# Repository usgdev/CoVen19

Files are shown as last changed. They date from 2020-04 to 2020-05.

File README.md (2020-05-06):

# CoVen19
Project CoVen19 is breathing ventilator developed using standard supply already available in market easily, can be manufactured in large quantities with lowest possible resources in pandemic scenario.

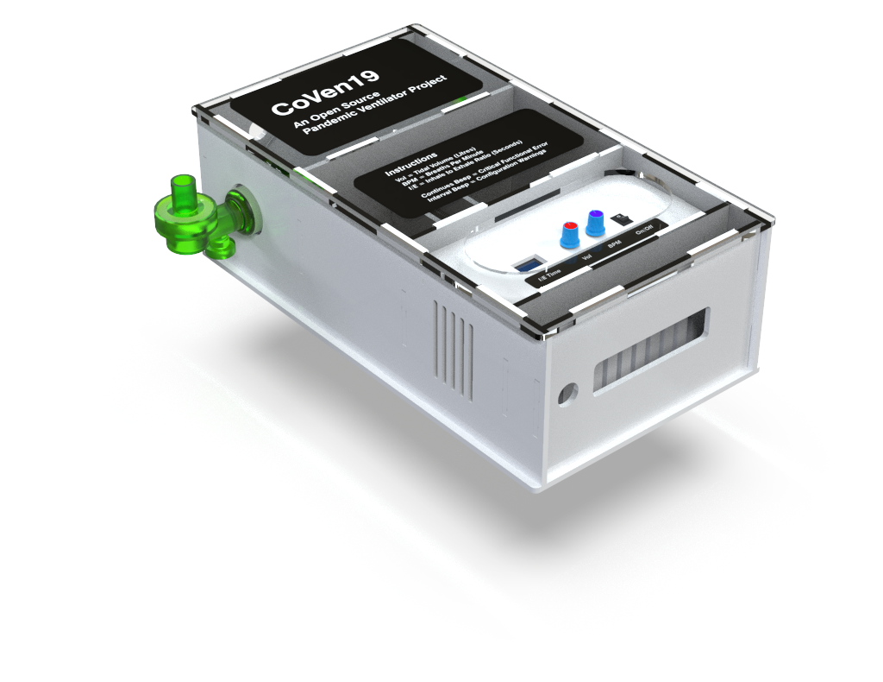
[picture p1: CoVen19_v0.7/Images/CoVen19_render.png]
CoVen19


# Current Development Version CoVen19 v0.7
CoVen19 v0.7 has following changes/updates as per latest commits:
- [x] DIY Actuator Assembly 2D DXF files Included
- [ ] Arduino UNO Firmware .ino file release(Source Code v0.7)
- [ ] Wiring schematics release(v0.7)
- [x] Updated 3D files in .STL file release
- [x] Simplified enclosure assembly design
- [x] Fixed Enclosure assembly Tab and Slot clearance
- [x] Updated BOM release in .xlsx file(v0.7)
- [x] Components reference images included

# Pandemic Ventilator Design Guideline
This is a specification of the minimally (and some preferred options) clinically acceptable ventilator to be
used in UK hospitals during the current SARS-CoV2 outbreak. It sets out the clinical requirements based on the consensus of what is ‘minimally acceptable’ performance in the opinion of the anaesthesia and intensive care medicine professionals and medical device regulators...Read more on official page https://www.gov.uk/government/publications/coronavirus-covid-19-ventilator-supply-specification/rapidly-manufactured-ventilator-system-specification

# Pandemic Ventilator Design Challenge
CoVen19 Design Challenge (https://www.youtube.com/watch?v=7vLPefHYWpY)

# What is PEEP? How to Deal with it!
## Graphics Content Warning: Demonstration video using body parts! Welcome to real medical world!
What is PEEP (https://www.youtube.com/watch?v=Gu4sChU9eBo)

# How BVM(Bag Valve Mask), PEEP Valves and Diverters works?

CoVen19 How BVM Works? (https://www.youtube.com/embed/Douv4EPk_jA)

# Source Code
### [Please find full source code here for v0.7](https://github.com/USGDEV/CoVen19/tree/master/SOURCE/Arduino/CoVen19_release_v0.7)

```C++

//Ventilator code 
//Version 1.0.0

//Breath Cycle parameters
int Inhalation_time_set[] = {1500, 1380, 1290, 1200, 1130, 1060, 1000, 950, 900}; //in milli seconds
int current_Inhalation_time = Inhalation_time_set[0];
const int current_Hold_Pause_time = 300; //Hold time does not change ever
int Exhalation_time_set[] = {3200, 2930, 2700, 2500, 2330, 2170, 2030, 1910, 1800}; //in milli seconds
int current_Exhalation_time = Exhalation_time_set[0];

//Air Volume control potentiometer parameters
int Actuator_displacement[] = {20, 40, 60, 80, 100}; //in mm
int corrent_Actuator_displacement = Actuator_displacement[0];

//Debug variables
boolean debug_output = true; //If false no serial output, to see output on serial true it

//Pin Definations
const int POT_BTH = A0;
const int POT_AVC = A1;

//Motor Related
//define Pins
int Step   =  6;
int Dir    =  7;
int MS1    =  4;
int MS2    =  5;

//define variables
int   direction        = 0;      //direction is either "0" or "1" to choose direction
float cycle            = 1;      //cycle can be in decimal 1 is 360 rotation and 0.5 is 180 degree
float time_for_cycles  = 0;      //time for total cycle is in milisecond so it can be in decimal

int   SelectResolution = 0;      //Resolution table given below
int   StepsPerRevo     = 0;

```

# Enclosure
Enclosure design based on laser cutting of 5mm acrylic or pvc sheet, normally available easily in market. 5mm sheet cutting is quick and sturdiness will be good enough to hold ventilator assembly all together, enclosure is essential to handle the ventilator without damaging internal parts.

### [Here is DXF 2D files provided for laser cutting v0.7](https://github.com/USGDEV/CoVen19/tree/master/CoVen19_v0.7/DXF)
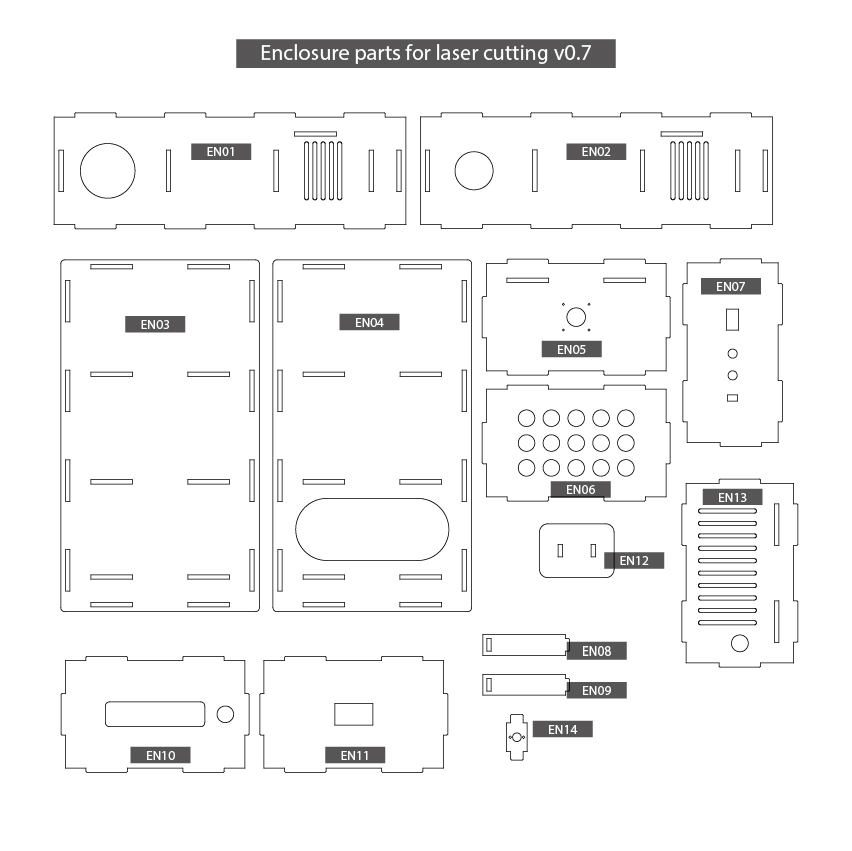
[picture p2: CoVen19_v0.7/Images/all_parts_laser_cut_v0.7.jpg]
CoVen19 Enclosure

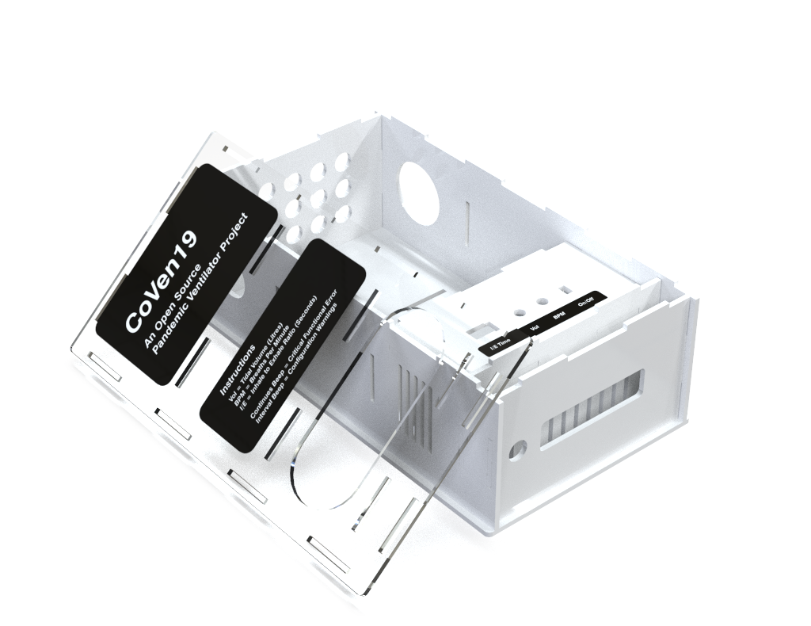
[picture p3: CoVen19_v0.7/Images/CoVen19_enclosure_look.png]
CoVen19 Enclosure


No. | ID | DXF File Name
------------ | ------------- | -------------
1 | EN01 | side_enclosure_right.DXF
2 | EN02 | side_enclosure_left.DXF
3 | EN03 | body_base_plate.DXF
4 | EN01 | body_enclosure_cover.DXF
5 | EN05 | nema_mount_plate.DXF
6 | EN06 | ambubag_air_release_plate.DXF
7 | EN07 | electronics_mount_panel.DXF
8 | EN08 | actuator_arm_left.DXF
9 | EN09 | actuator_arm_right.DXF
10 | EN10 | body_handle_plate.DXF
11 | EN11 | actuator_support_plate.DXF
12 | EN12 | pressure_plate_sloted.DXF
13 | EN13 | body_safety_plate.DXF
14 | EN14 | nut_connector_plate.DXF
    
# Components Used

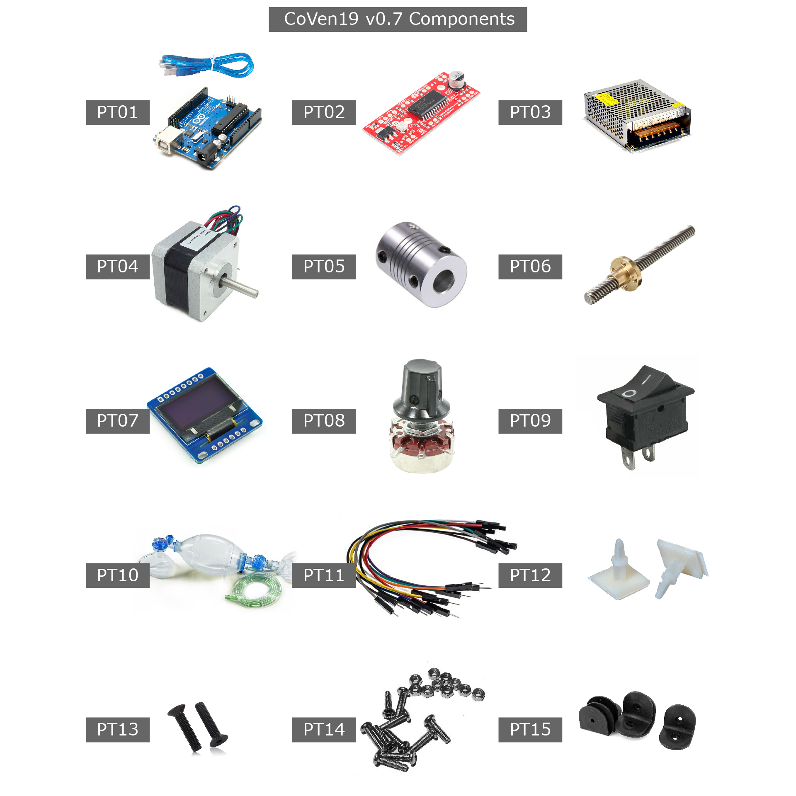
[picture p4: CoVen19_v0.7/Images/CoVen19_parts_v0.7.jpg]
CoVen19 Enclosure


No. | ID | Part Name | Ref Links/Remarks
------------ | ------------ | ------------- | -------------
1 | PT01 | Arduino UNO R3 | https://store.arduino.cc/usa/arduino-uno-rev3
2 | PT02 | SparkFun EasyDriver | https://www.sparkfun.com/products/12779
3 | PT03 | 12v Power Supply | https://www.amazon.com/MEAN-WELL-RD-65A-Output-Enclosed/dp/B005T7EZM8/
4 | PT04 | NEMA 17 Motor | Link
5 | PT05 | 5mmX8mm Coupler | Link
6 | PT06 | 8mmX100mm Lead Screw | Link
7 | PT07 | OLED 128X64 Display | Link
8 | PT08 | 100K Potentiometer | Link
9 | PT09 | Rocker Switch | Link
10 | PT10 | BVM Ambubag 350~450ml | Link
11 | PT11 | Jumper Wires | Link
12 | PT12 | PCB Self Adhesive Mounts | Link
13 | PT13 | M3X8mm Nema Mount Screw | Link
14 | PT14 | M3X10mm Bracket Nut-Bolt | Link
15 | PT15 | 90 Degree Brackets | Link

## Detailed BOM for v0.7 can be found [HERE](https://github.com/USGDEV/CoVen19/blob/master/CoVen19_v0.7/BOM/CoVen19_BOM_v0.7_r1.xlsx).

## Important Note:
**Above listed links are just for reference, You can buy components from any where you wish to.**

# Testing Equipments (Not a Part of CoVen19)
You can get a testing lungs that mimics some functions of human lung for testing your ventilator, [here is example link.](https://www.amazon.com/gp/product/B0767RBQ1H)

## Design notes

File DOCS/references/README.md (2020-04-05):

<h1>Useful Reference Links</h1>

Similar Open Source Projects
https://oedk.rice.edu/apollobvm/

<h2>Install Guides</h2>

Arduino IDE Guide
https://www.arduino.cc/en/Guide/windows

Visual Studio Install Guide (Optional)
https://www.dmcinfo.com/latest-thinking/blog/id/9484/arduino-programming-with-vscode

<h2>Arduino Code Examples</h2>

Stepper Motor Controller with SparkFun EasyDriver 
https://rudysarduinoprojects.wordpress.com/2019/07/08/fun-with-arduino-37-control-a-nema-17-stepper-motor-with-easy-driver/

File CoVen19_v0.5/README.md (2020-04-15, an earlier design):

# CoVen19 Version 0.7

# CoVen19
Project CoVen19 is breathing ventilator developed using standard supply already available in market easily, can be manufactured in large quantities with lowest possible resources in pandemic scenario.

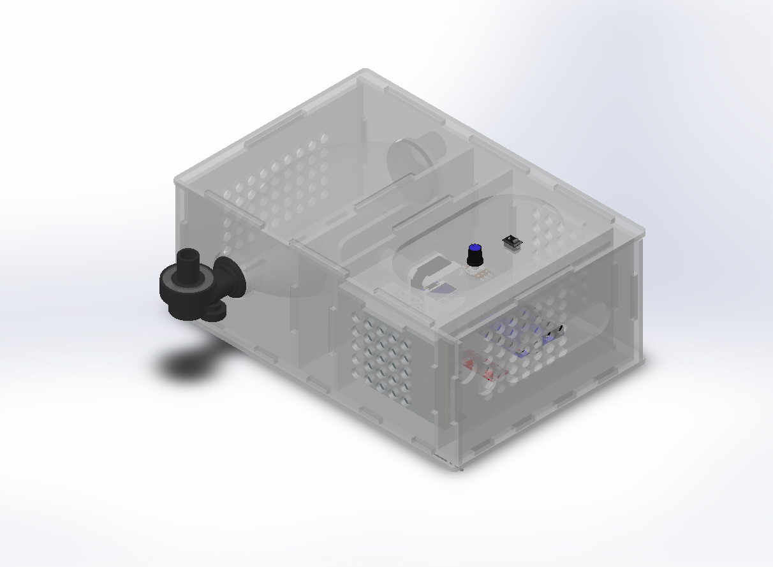
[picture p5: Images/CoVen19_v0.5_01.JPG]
CoVen19


# Pandemic Ventilator Design Guideline
This is a specification of the minimally (and some preferred options) clinically acceptable ventilator to be
used in UK hospitals during the current SARS-CoV2 outbreak. It sets out the clinical requirements based on the consensus of what is ‘minimally acceptable’ performance in the opinion of the anaesthesia and intensive care medicine professionals and medical device regulators...Read more on official page https://www.gov.uk/government/publications/coronavirus-covid-19-ventilator-supply-specification/rapidly-manufactured-ventilator-system-specification

# Pandemic Ventilator Design Challenge
CoVen19 Design Challenge (https://www.youtube.com/watch?v=7vLPefHYWpY)

# What is PEEP? How to Deal with it!
## Graphics Content Warning: Demonstration video using body parts! Welcome to real medical world!
What is PEEP (https://www.youtube.com/watch?v=Gu4sChU9eBo)

# How BVM(Bag Valve Mask), PEEP Valves and Diverters works?

CoVen19 How BVM Works? (https://www.youtube.com/embed/Douv4EPk_jA)

# Source Code
### [Please find full source code here for v0.5](https://github.com/USGDEV/CoVen19/tree/master/SOURCE/Arduino/CoVen19_release_v0.5)

```C++

//Forward/reverse stepping function
void ForwardBackwardStep()
{
  Serial.println("Alternate between stepping forward and reverse.");
  for(x= 1; x<5; x++)  //Loop the forward stepping enough times for motion to be visible
  {
    //Read direction pin state and change it
    state=digitalRead(dir);
    if(state == HIGH)
    {
      digitalWrite(dir, LOW);
    }
    else if(state ==LOW)
    {
      digitalWrite(dir,HIGH);
    }

    for(y=0; y<1000; y++)
    {
      digitalWrite(stp,HIGH); //Trigger one step
      delay(1);
      digitalWrite(stp,LOW); //Pull step pin low so it can be triggered again
      delay(1);
    }
  }
  Serial.println("Enter new option:");
  Serial.println();
}

```

# Enclosure
Enclosure design based on laser cutting of 5mm acrylic or pvc sheet, normally available easily in market. 5mm sheet cutting is quick and sturdiness will be good enough to hold ventilator assembly all together, enclosure is essential to handle the ventilator without damaging internal parts.

### [Here is DXF 2D files provided for laser cutting v0.5](https://github.com/USGDEV/CoVen19/tree/master/DXF/Laser_Cut_v0.5)

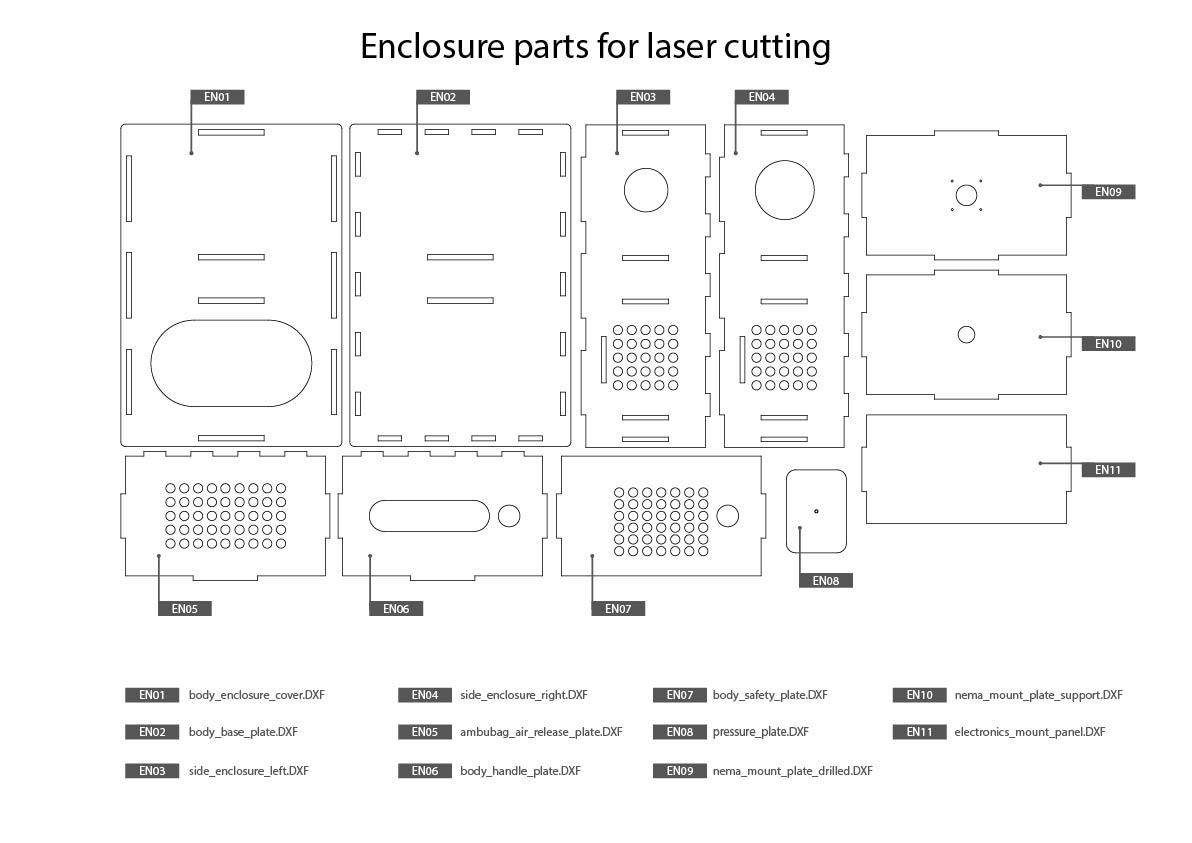
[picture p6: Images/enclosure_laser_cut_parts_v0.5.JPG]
CoVen19 Enclosure


1. ambubag_air_release_plate.DXF
2. body_base_plate.DXF
3. body_enclosure_cover.DXF
4. body_handle_plate.DXF
5. body_safety_plate_.DXF
6. electronics_mount_panel.DXF
7. nema_mount_plate_drilled.DXF
8. nema_mount_plate_support.DXF
9. pressure_plate.DXF
10. side_enclosure_left.DXF
11. side_enclosure_right.DXF

### Important Note:
**CoVen19 v0.5 enclosure design compatible with stepper motor model [LGA421S14-A-UIEV-038](https://us.nanotec.com/products/2782-lga421s14-a-uiev-038/) or motor with similar specification in order to actuator length, motor/mount screw dimensions etc. Please make sure that the stepper motor you are using is similar. OR make necessary changes to DXF files.**

LGA42 motor

Please refer detailed document and information [here](https://us.nanotec.com/products/2782-lga421s14-a-uiev-038/)

# Components Used

Component Name | Ref Links
------------ | -------------
NEMA LGA42 Motor | https://us.nanotec.com/products/2782-lga421s14-a-uiev-038/
Arduino UNO r3 | https://store.arduino.cc/usa/arduino-uno-rev3
SparkFun EasyDriver | https://www.sparkfun.com/products/12779
Generic Power Supply | https://www.amazon.com/MEAN-WELL-RD-65A-Output-Enclosed/dp/B005T7EZM8/
Ambu Bag (BVM) | https://www.amazon.com/Adult-Simple-Breathing-Apparatus-Kit/dp/B085ZLVMZ3/
Mains Power Supply Cable | https://www.secomp-international.com/en_US/roline-power-cable-with-schuko-connector-open-end-ac-230v-bl/i/19.08.1111-10
OLED Display | https://www.amazon.com/dp/B00O2LLT30
Rotary Potentiometer | https://www.amazon.in/pack-potentiometer-single-variable-resistor/dp/B07L3YQ4NT
Black Metal Knob | https://www.sparkfun.com/products/10002
Rocker Switch | https://www.sparkfun.com/products/8837
M3 Screw 8mm | https://www.amazon.com/dp/B01IWUSDYY and https://www.amazon.com/uxcell-M3x8mm-Thread-Button-Socket/dp/B01B1OD62C
90 Degree Bracket Joint | https://www.ebay.com/itm/90-Degree-Right-Angle-Stainless-Steel-Support-Shelf-Bracket-Joint-Corner-Brace-/183693072726
Acrylic sheet | https://www.amazon.com/dp/B07MWXWDKQ

### Important Note:
**Above listed links are just for reference, You can buy components from any where you wish to.**

# Testing Equipments (Not a Part of CoVen19)
You can get a testing lungs that mimics some functions of human lung for testing your ventilator, [here is example link.](https://www.amazon.com/gp/product/B0767RBQ1H)

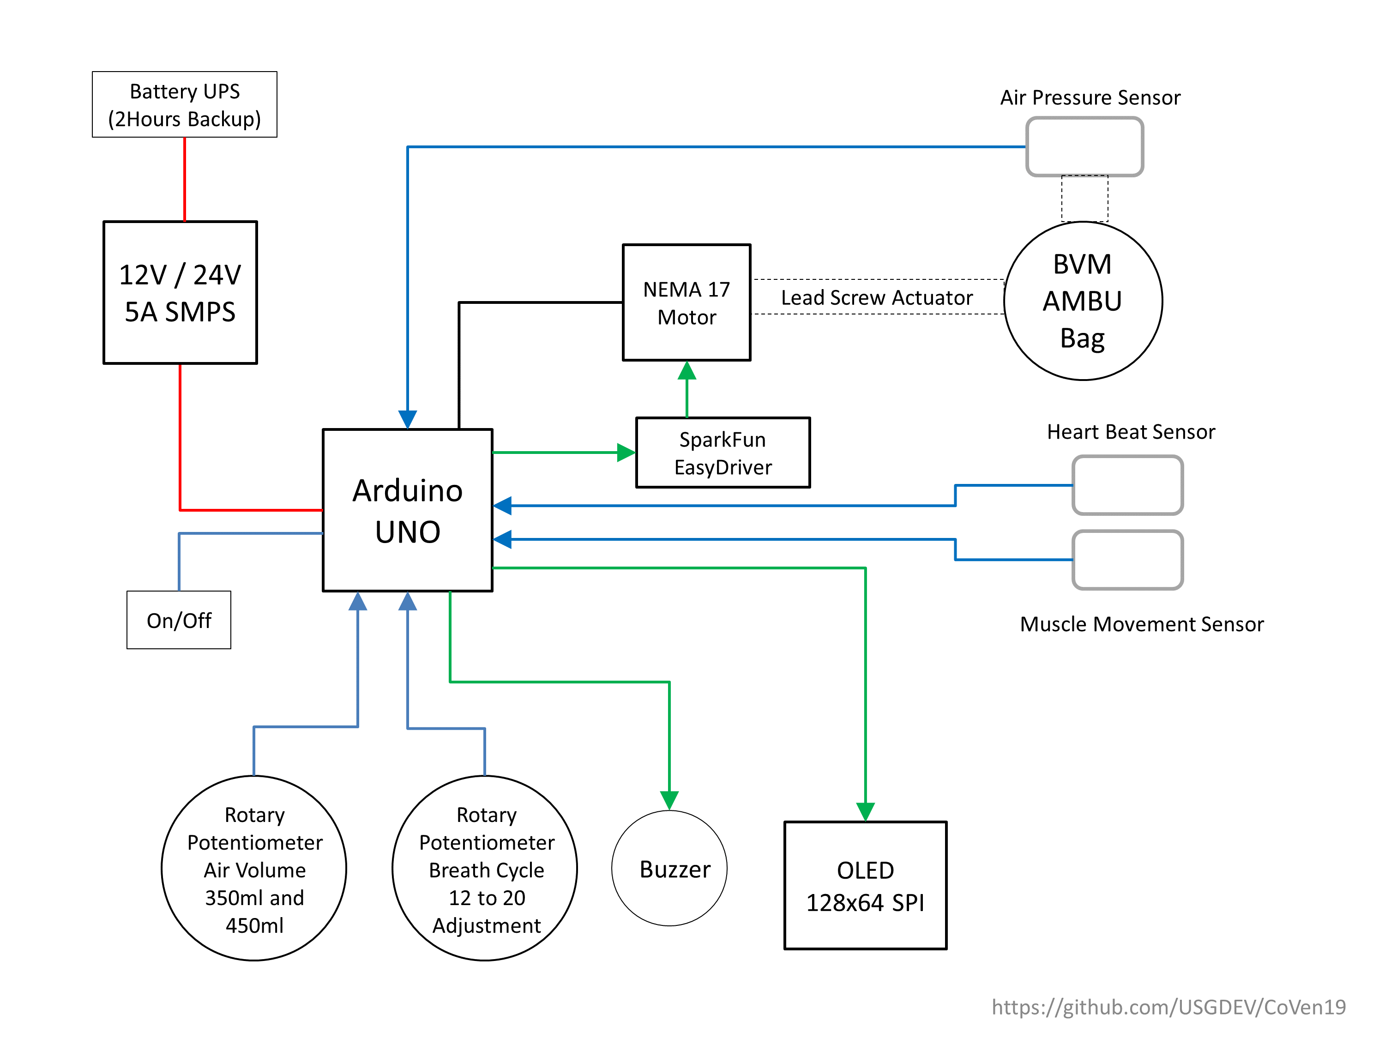
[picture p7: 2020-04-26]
DOCS/CoVen19_block_diagram_v1.png

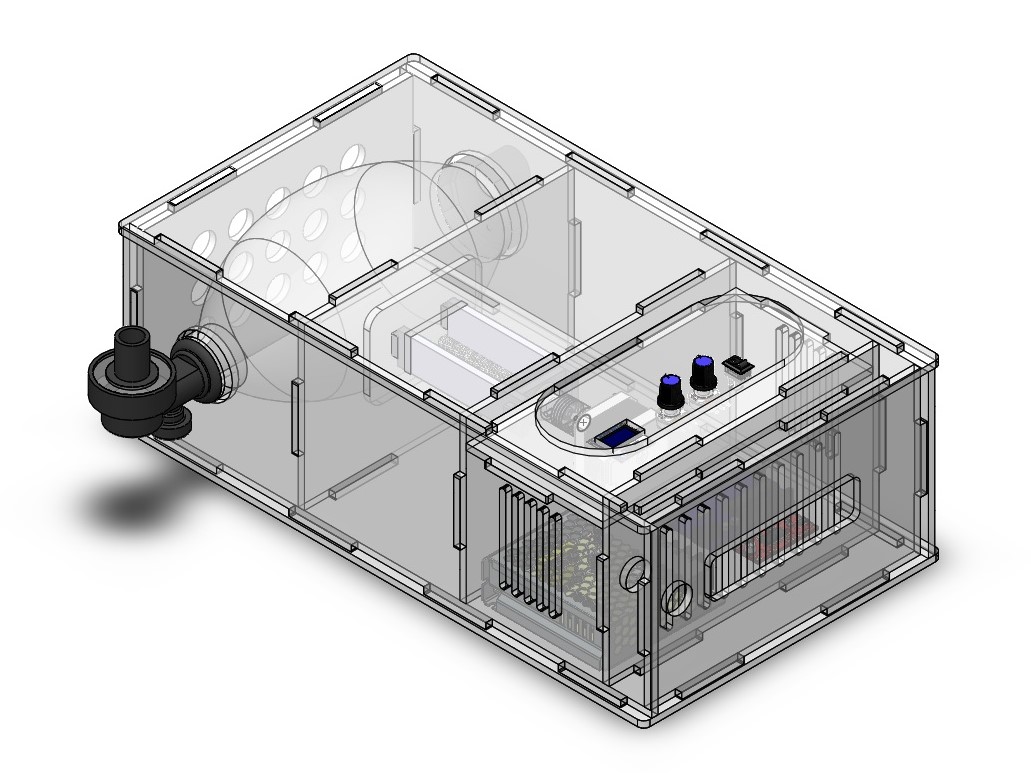
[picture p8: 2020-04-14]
CoVen19_v0.7/Images/CoVen19_v0.7_01.JPG

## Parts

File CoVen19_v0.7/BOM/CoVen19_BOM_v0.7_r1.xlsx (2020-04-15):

Sr. No. | Part Name | PART SKU/ID/Discription | Qty. | Procurement Link(s) | Remarks
 | NEMA 17 Motor | Stepper motor - NEMA-17 size - 200 steps/rev, 12V 350mA PRODUCT ID: 324 | 1 | https://www.adafruit.com/product/324
 | Arduino UNO r3 | ARDUINO UNO REV3 Code: 8058333490090 | 1 | https://store.arduino.cc/usa/arduino-uno-rev3
 | SparkFun EasyDriver | EasyDriver - Stepper Motor Driver | 1 | https://www.sparkfun.com/products/12779
 | Generic Power Supply | 12V, 3.5 Amp Single Output Switching Power Supply (Item #PS1-40W-SL12) | 1 | https://www.circuitspecialists.com/12-volt-3.5-amp-power-supply.html
 | Ambu Bag (BVM) | Generic Adult BVM Ambu Bag | 1 | https://www.amazon.com/Silica-Manual-Simple-Breathing-Oxygen/dp/B0862CL1YB?me= | Any BVM adult Ambu Bag Should Work
 | Mains Power Supply Cable | Generic Power supply cable | 1
 | OLED Display | Generic Arduino Compitible OLED 128x64 Display | 1 | https://www.dnatechindia.com/6-pin-128-64-white-oled-display.html
 | Rotary Potentiometer | Rotary Potentiometer | 1 | https://www.sparkfun.com/products/9939
 | Black Metal Knob | Black Metal Knob - 14x24mm | 1 | https://www.sparkfun.com/products/10002
 | Rocker Switch | Rocker Switch | 1 | https://www.sparkfun.com/products/8837
 | M3 Screw 8mm | M3 Screw 8mm screw for nema 17 motor mounting | 4 | https://www.aliexpress.com/item/32778526710.html
 | 90 Degree Bracket Joints | Brackets for securing enclosure parts | 10 | https://www.ebay.com/itm/90-Degree-Right-Angle-Stainless-Steel-Support-Shelf-Bracket-Joint-Corner-Brace-/183693072726 | Approx
 | Screw for Braket Joints | Generic nut bots compitibal with Bracket | 60
 | Acrylic sheet | 5 mm acrylic sheet for laser cutting |  |  | Laser cutting as per DXF file provided with this project

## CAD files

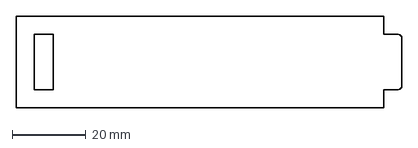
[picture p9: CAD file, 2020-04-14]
CoVen19_v0.7/DXF/actuator_arm_left.DXF
105.0 x 25.0 mm

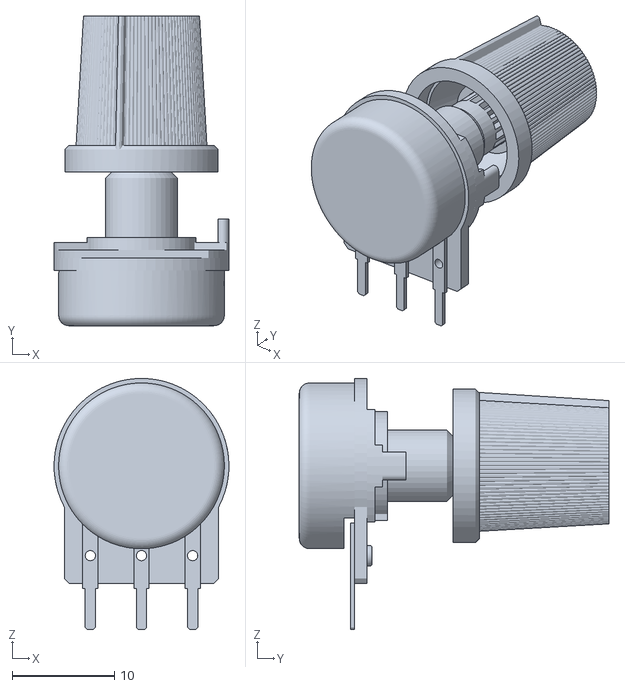
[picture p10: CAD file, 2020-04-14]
CoVen19_v0.7/STL/potentiometer_breathing_speed-1.STL
17.1 x 30.3 x 24.5

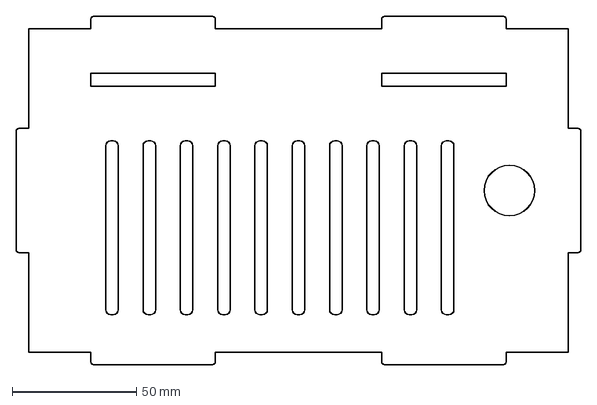
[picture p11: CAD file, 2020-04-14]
CoVen19_v0.7/DXF/body_safety_plate.DXF
227.0 x 140.0 mm

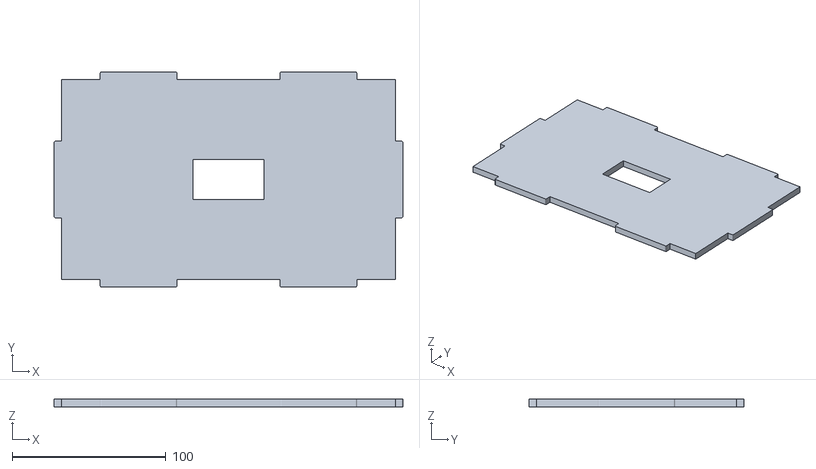
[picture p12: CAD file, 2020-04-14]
CoVen19_v0.7/STL/actuator_support_plate-1.STL
227.0 x 140.0 x 5.00

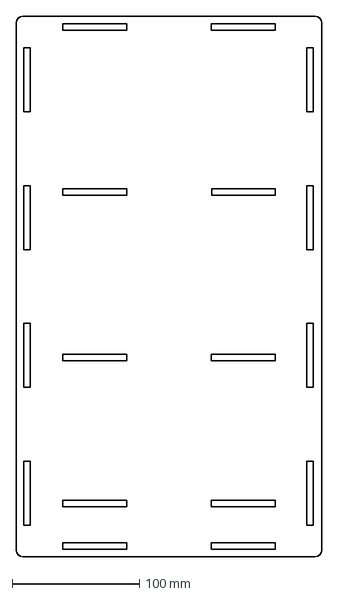
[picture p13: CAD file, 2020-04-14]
CoVen19_v0.7/DXF/body_base_plate.DXF
240.0 x 425.0 mm

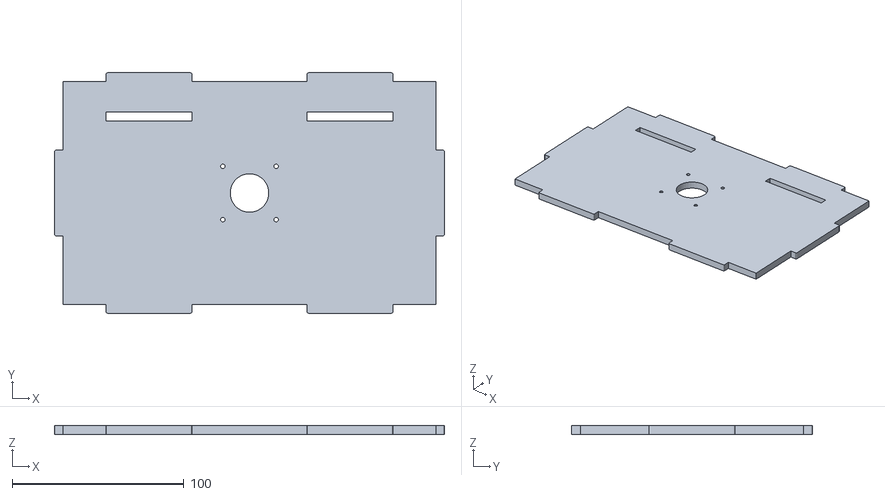
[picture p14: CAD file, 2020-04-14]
CoVen19_v0.7/STL/nema_mount_plate-1.STL
227.0 x 140.0 x 5.00

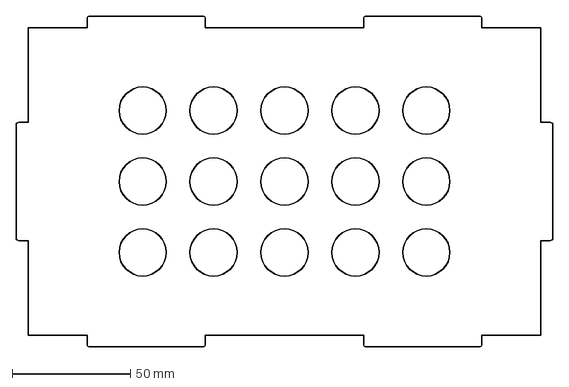
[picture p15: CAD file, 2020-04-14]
CoVen19_v0.7/DXF/ambubag_air_release_plate.DXF
227.0 x 140.0 mm

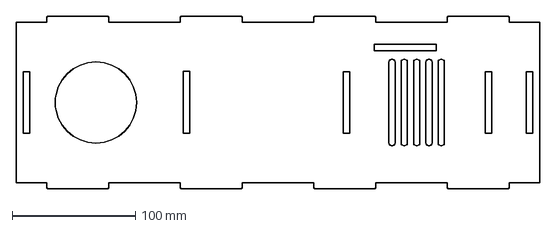
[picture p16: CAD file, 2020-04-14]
CoVen19_v0.7/DXF/side_enclosure_right.DXF
425.0 x 140.0 mm

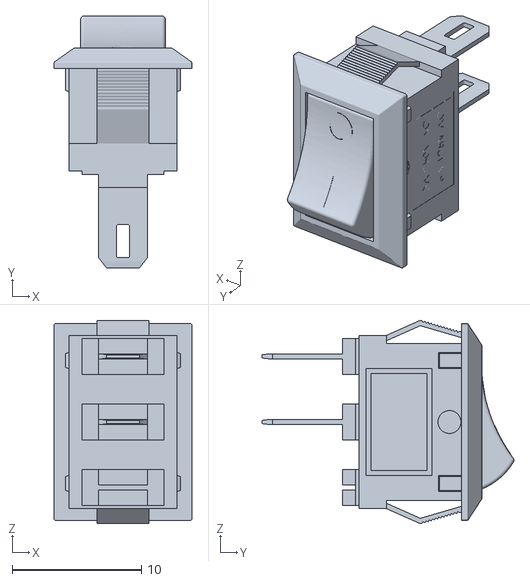
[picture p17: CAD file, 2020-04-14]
CoVen19_v0.7/STL/Rocker_Switch-1.STL
10.7 x 19.5 x 15.7

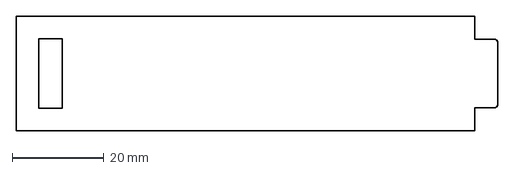
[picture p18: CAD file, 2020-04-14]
CoVen19_v0.7/DXF/actuator_arm_right.DXF
105.0 x 25.0 mm

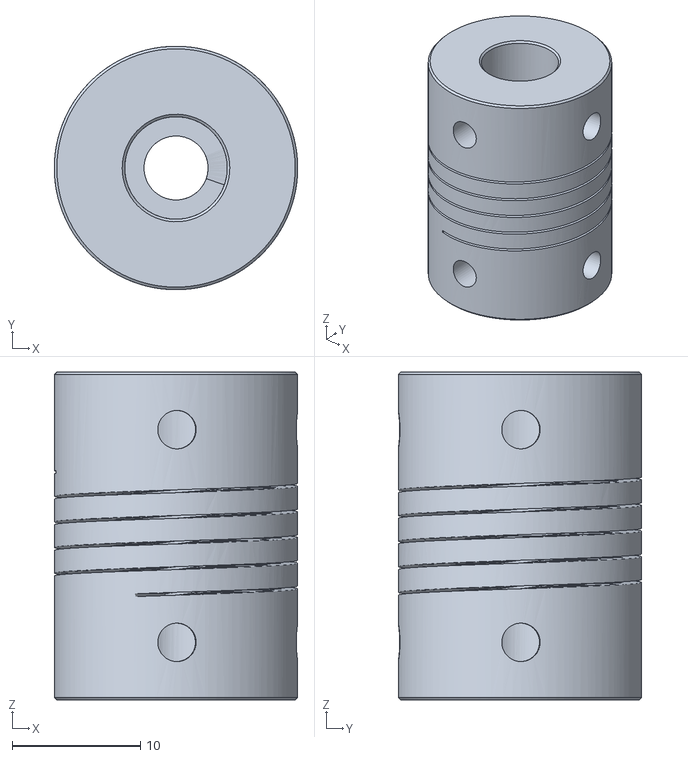
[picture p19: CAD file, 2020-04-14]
CoVen19_v0.7/STL/nema_coupler_5x8mm-1.STL
19.0 x 19.0 x 25.6

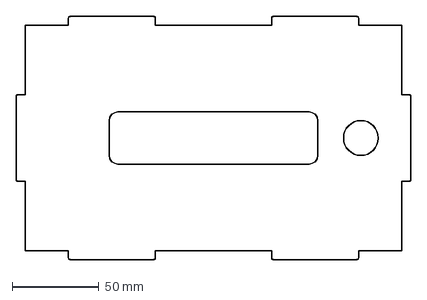
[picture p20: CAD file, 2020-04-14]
CoVen19_v0.7/DXF/body_handle_plate.DXF
227.0 x 140.0 mm

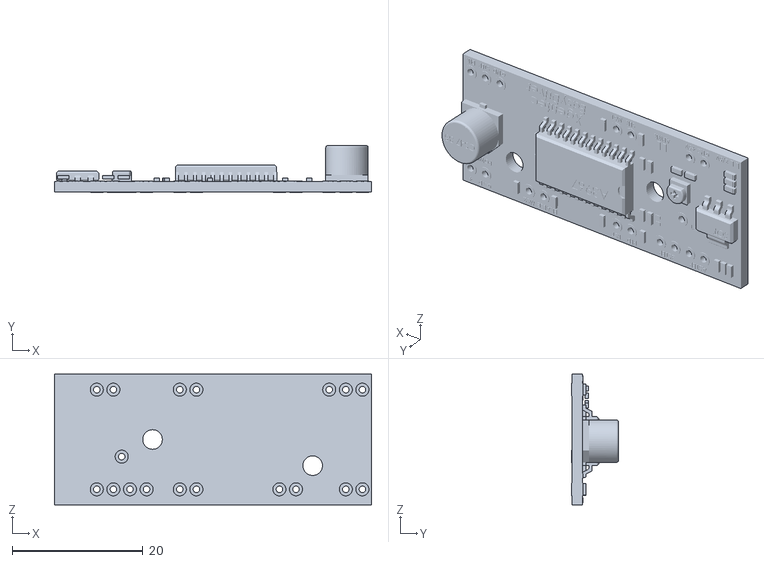
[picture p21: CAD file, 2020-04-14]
CoVen19_v0.7/STL/Easy_Driver-1.STL
48.5 x 7.21 x 20.0

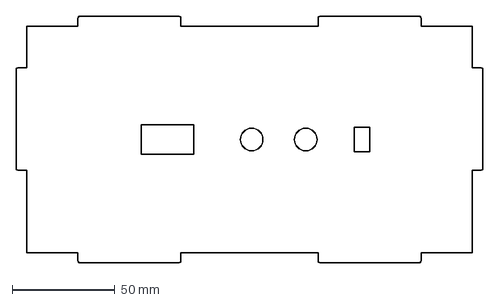
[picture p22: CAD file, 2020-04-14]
CoVen19_v0.7/DXF/electronics_mount_panel.DXF
227.0 x 120.0 mm

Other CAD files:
CoVen19_v0.7/STL/body_enclosure_cover-1.STL
CoVen19_v0.7/DXF/side_enclosure_left.DXF
CoVen19_v0.7/STL/arduino_Uno_r3-1.STL
CoVen19_v0.7/DXF/nema_mount_plate.DXF
CoVen19_v0.5/DXF/ambubag_air_release_plate.DXF
CoVen19_v0.5/DXF/body_base_plate.DXF
CoVen19_v0.5/DXF/body_enclosure_cover.DXF
CoVen19_v0.5/DXF/body_handle_plate.DXF
CoVen19_v0.5/DXF/body_safety_plate_.DXF
CoVen19_v0.5/DXF/electronics_mount_panel.DXF
CoVen19_v0.5/DXF/enclouser_laser_cut_parts_v0.5.dxf
CoVen19_v0.5/DXF/nema_mount_plate_drilled.DXF
CoVen19_v0.5/DXF/nema_mount_plate_support.DXF
CoVen19_v0.5/DXF/pressure_plate.DXF
CoVen19_v0.5/DXF/side_enclosure_left.DXF
CoVen19_v0.5/DXF/side_enclosure_right.DXF
CoVen19_v0.5/STL/STL_v0.5/CoVen19 - CoVen_control_panel_v0.5-1 OLED_128x64-1.STL
CoVen19_v0.5/STL/STL_v0.5/CoVen19 - CoVen_control_panel_v0.5-1 Rocker_Switch-1.STL
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

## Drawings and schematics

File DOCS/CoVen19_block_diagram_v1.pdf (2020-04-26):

## BVM

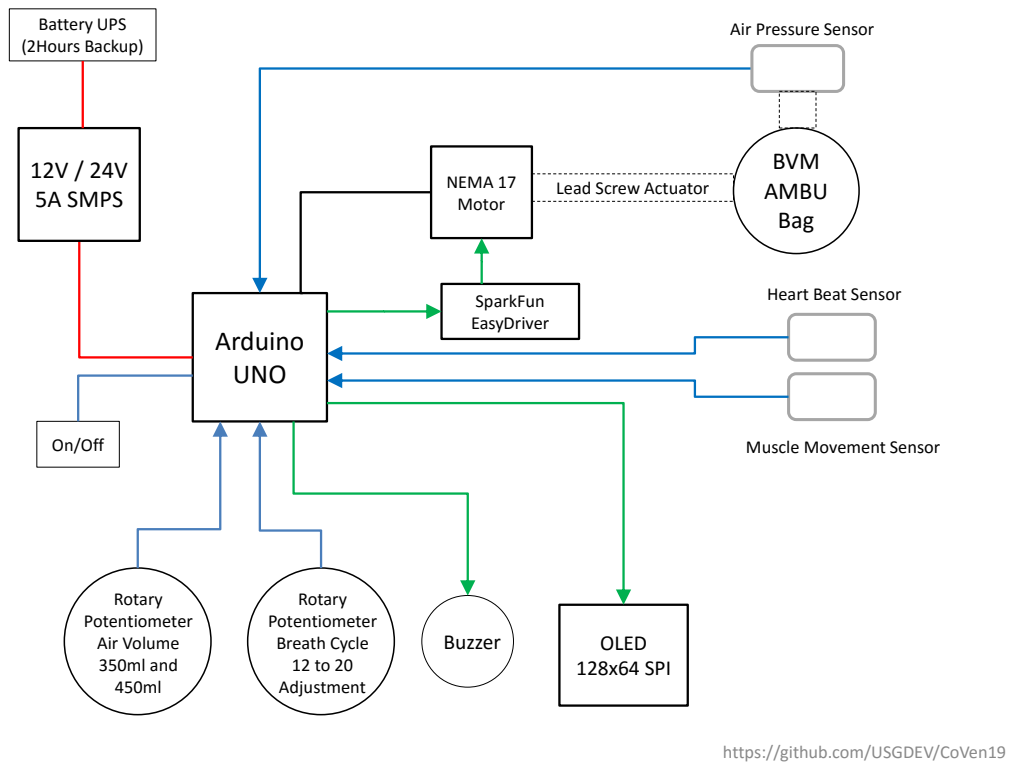
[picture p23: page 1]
SparkFun EasyDriver; Arduino UNO; OLED 128x64 SPI; On/Off; Buzzer; Rotary Potentiometer Air Volume 350ml and 450ml; Rotary Potentiometer Breath Cycle 12 to 20 Adjustment; 12V / 24V 5A SMPS; Battery UPS (2Hours Backup); NEMA 17 Motor; AMBU Bag

Air Pressure Sensor

Lead Screw Actuator

Heart Beat Sensor

Muscle Movement Sensor

https://github.com/USGDEV/CoVen19

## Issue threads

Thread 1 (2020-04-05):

Arduino UNO code verification

USGDEV, 2020-04-05:
Hi Devs,

Please update and verify Arduino UNO codes as per following requirements ;

**Code Link**
https://github.com/USGDEV/CoVen19/tree/master/SOURCE/Arduino

**Ref Link**
https://rudysarduinoprojects.wordpress.com/2019/07/08/fun-with-arduino-37-control-a-nema-17-stepper-motor-with-easy-driver/

Hook up Arduino UNO, SparkFun EasyDriver, 100uK(or may be other value) Potentiometer, OLED 128x64 and NEMA 17 12v Motor. (or using Arduino simulator)

Cycle steps
1. NEMA 17 actuator at minimum (0mm) position.
2. Actuator start expanding from 0mm to approx 50 mm in 1 second.
3. Hold actuator 50mm position for 1 second.
4. Retract back actuator to 0 position in 0.5 second.
5. Hold for 0.5 second at 0mm position.

repeat these steps in function loop

Thanks

USGDEV, 2020-04-06:
few projects with code example

https://github.com/Inspire-Poli-USP/Inspire-OpenLung/blob/master/OpenLung-firmware/OpenLung-firmware.ino

https://github.com/ermtl/Open-Source-Ventilator/blob/master/OpenSourceVentilator/OpenSourceVentilator.ino

Closed 2020-05-05.

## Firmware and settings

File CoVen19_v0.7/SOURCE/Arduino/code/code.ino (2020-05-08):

//Ventilator code 
//Version 0.7

//Breath Cycle parameters
int Inhalation_time_set[] = {1500, 1380, 1290, 1200, 1130, 1060, 1000, 950, 900}; //in milli seconds
int current_Inhalation_time = Inhalation_time_set[0];
const int current_Hold_Pause_time = 300; //Hold time does not change ever
int Exhalation_time_set[] = {3200, 2930, 2700, 2500, 2330, 2170, 2030, 1910, 1800}; //in milli seconds
int current_Exhalation_time = Exhalation_time_set[0];

//Air Volume control potentiometer parameters
int Actuator_displacement[] = {20, 40, 60, 80, 100}; //in mm
int corrent_Actuator_displacement = Actuator_displacement[0];

//Debug variables
boolean debug_output = true; //If false no serial output, to see output on serial true it


//Pin Definations
const int POT_BTH = A0;
const int POT_AVC = A1;



//Motor Related
//define Pins
int Step   =  6;
int Dir    =  7;
int MS1    =  4;
int MS2    =  5;

//define variables
int   direction        = 0;      //direction is either "0" or "1" to choose direction
float cycle            = 1;      //cycle can be in decimal 1 is 360 rotation and 0.5 is 180 degree
float time_for_cycles  = 0;      //time for total cycle is in milisecond so it can be in decimal

int   SelectResolution = 0;      //Resolution table given below
int   StepsPerRevo     = 0;


/*                   SelectResolution   MS1   MS2   Microstep Resolution
                             0           L     L     Full Step (2 Phase)
                             1           H     L     Half Step
                             2           L     H     Quarter Step
                             3           H     H     Eigth Step                                            */

void setup() {
  // put your setup code here, to run once:
  Serial.begin(115200);
  pinMode(POT_BTH, INPUT);
  pinMode(POT_AVC, INPUT);
  init_motor_parameter();

}

void loop() {
  // put your main code here, to run repeatedly:
  BCM_motion();

}

void BCM_motion() { //Breath cycle movement
  //First set motor paramter according to BCP
  set_BCM_parameter(set_breath_cycles_virtual_set());
  set_AVC_parameter(set_air_volume_control_set());
  //Now rotate motor accordingly
  motor_Expansion_actuator_Inhalation();
  BCM_motor_hold();
  motor_retraction_actuator_Exhalation();
}

void motor_Expansion_actuator_Inhalation() {
  debug_msg_print("Inhalation:" + String(corrent_Actuator_displacement) + ":" + String(current_Inhalation_time));
  motor_rotate(0 , corrent_Actuator_displacement , current_Inhalation_time);
}

void motor_retraction_actuator_Exhalation() {
  debug_msg_print("Exhalation:" + String(corrent_Actuator_displacement) + ":" + String(current_Exhalation_time));
  motor_rotate(1 , corrent_Actuator_displacement , current_Exhalation_time);
}

void BCM_motor_hold() {
  debug_msg_print("Hold:300");
  motor_stop();
  delay(300);
}

void init_motor_parameter() {
  pinMode(Step, OUTPUT);
  pinMode(Dir , OUTPUT);
  pinMode(MS1  , OUTPUT);
  pinMode(MS2  , OUTPUT);

  if ( SelectResolution == 0 ) {
    digitalWrite(MS1 , LOW);
    digitalWrite(MS2 , LOW);
    StepsPerRevo =  200;
  }
  if ( SelectResolution == 1 ) {
    digitalWrite(MS1 , HIGH);
    digitalWrite(MS2 , LOW);
    StepsPerRevo =  400;       //200*2
  }
  if ( SelectResolution == 2 ) {
    digitalWrite(MS1 , LOW);
    digitalWrite(MS2 , HIGH);
    StepsPerRevo =  800;       //200*4
  }
  if ( SelectResolution == 3 ) {
    digitalWrite(MS1 , HIGH);
    digitalWrite(MS2 , HIGH);
    StepsPerRevo =  1600;       //200*8
  }
}

void motor_stop() {
  digitalWrite(Step , HIGH);
  delayMicroseconds(100);
  digitalWrite(Step , HIGH );
  delayMicroseconds(100);
}

void motor_rotate(int direction_pass, float cycles_pass, float time_for_cycles_pass) {

  if ( direction_pass == 0) {
    digitalWrite( Dir , HIGH );
  }
  else {
    digitalWrite( Dir , LOW );
  }

  float StepsProduCycle       = StepsPerRevo * cycles_pass;        //if steps per revolution is 200 and cycle is 2 then it is 400 means 360*2= 720 degree rotation
  float ConvertMicroSecCycle  = 1000 * time_for_cycles_pass;       //Convert in Microseconds for accuracy
  float OneCycleTime          = ConvertMicroSecCycle / cycles_pass; //For one ccle time
  float PulseTotaltime        = OneCycleTime / StepsPerRevo;       //one pulse Low and High time
  float Pulsetime             = PulseTotaltime / 2;                //Divide by 2, to divide pulse on off time
  //Serial.println(Pulsetime);
  for (int i = 0; i < StepsProduCycle ; i++) {
    digitalWrite(Step , HIGH);
    delayMicroseconds(Pulsetime);
    digitalWrite(Step , LOW );
    delayMicroseconds(Pulsetime);
  }

}

int set_air_volume_control_set() {
  int ADC_POT_AVC = analogRead(POT_AVC);
  int DIG_POT_AVC = map(ADC_POT_AVC , 0 , 1023, 0 , 360);
  switch (DIG_POT_AVC) {
    case 0 ... 72:
      return  1;
    case 73 ... 144:
      return  2;
    case 145 ... 216:
      return  3;
    case 217 ... 288:
      return  4;
    case 289 ... 360:
      return  5;
    default:
      return  0;  //0 means error
      break;
  }
}

int set_breath_cycles_virtual_set() {
  int ADC_POT_BCM = analogRead(POT_BTH);
  int DIG_ROT_BCM = map(ADC_POT_BCM , 0 , 1023, 0 , 360);
  switch (DIG_ROT_BCM) {
    case 0 ... 40:
      return  1;
    case 41 ... 80:
      return  2;
    case 81 ... 120:
      return  3;
    case 121 ... 160:
      return  4;
    case 161 ... 200:
      return  5;
    case 201 ... 240:
      return  6;
    case 241 ... 280:
      return  7;
    case 281 ... 320:
      return  8;
    case 321 ... 360:
      return  9;
    default:
      return  0;  //0 means error
      break;

  }
}

void set_AVC_parameter(int virtual_set) {
  if (virtual_set == 0) {
    debug_msg_print("Something wrong in setting virtual set");
  }
  else {
    corrent_Actuator_displacement = Actuator_displacement[virtual_set - 1];
  }
}

void set_BCM_parameter(int virtual_set) {
  if (virtual_set == 0) {
    debug_msg_print("Something wrong in setting virtual set");
  }
  else {
    current_Inhalation_time = Inhalation_time_set[virtual_set - 1];
    current_Exhalation_time = Exhalation_time_set[virtual_set - 1];
  }
}

void debug_msg_print(String debug_msg) {
  if (debug_output == true) {
    Serial.println(debug_msg);
  }

}

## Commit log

2020-04-08 Link Updates
    [CoVen19_BOM_v0.5_r1.xlsx]
2020-04-14 v0.7 Updates
    [CoVen19 - CoVen_control_panel_v0.5-1 OLED_128x64-1.STL, CoVen19 - CoVen_control_panel_v0.5-1 Rocker_Switch-1.STL, CoVen19 - CoVen_control_panel_v0.5-1 electron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]
2020-05-08 Added arduino code
